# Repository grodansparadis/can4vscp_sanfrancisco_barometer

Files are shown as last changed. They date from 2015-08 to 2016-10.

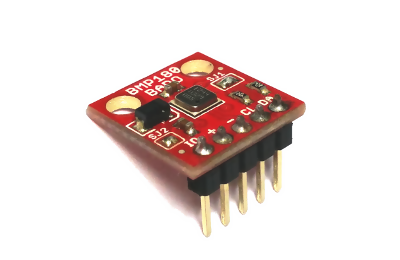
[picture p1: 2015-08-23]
docs/BMP180 Barometric Pressure Sensor Hookup - learn.sparkfun.com_files/52ce00f3ce395fc7238b4567.png

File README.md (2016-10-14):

<h1>CAN4VSCP San Franscisco - barometer module</h1>

VSCP Barometer module.

<hr>

This project is part of the <a href="http://www.vscp.org">VSCP (Very Simple Control Protocol) project</a>. 

<hr>

This project is licensed under the 
<a href="http://creativecommons.org/licenses/by-nc-sa/3.0/">Creative Commons open source license Attribution-NonCommercial-ShareAlike 3.0 Unported</a>. 
Other license options are available by conacting <a href="malto:info@grodansparadis.com">Paradis of the Frog AB</a>

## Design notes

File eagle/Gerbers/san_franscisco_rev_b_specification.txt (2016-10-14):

Ake Hedman
Grodans Paradis AB

Date:				2014-06-18
Part Number: 		San Francisco
Number of boards: 	120
Number of layers: 	2 
Material: 			FR4
Final Thickness:	1.6 mm
Final copper:		1/1oz
Surface treatment: 	ENIG
Unit Size:			72 x 42 mm
Panel Size:			154*126 mm
Unit/panel:			6
Solder Mask:		Green
Silk Screen: 		White	
Outline Profile:	CNC Routing + V-cut
X-out Allowed:		1
Stencil needed:		yes
Gerber layer for Stencil: Component Cream (pmc)

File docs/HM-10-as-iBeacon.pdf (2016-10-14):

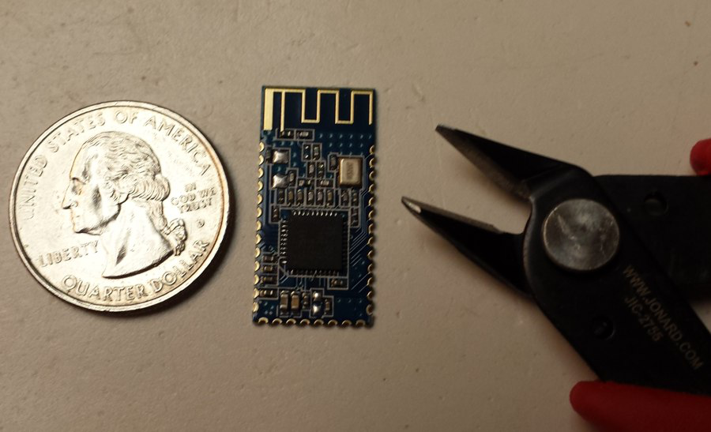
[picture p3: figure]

http://www.blueluminance.com/HM-10-as-iBeacon.pdf V3 | Page 1

## Using HM-10 BLE Modules as Low-Cost iBeacons

This document will describe how to use an HM-10 Bluetooth 4.0 module as an iBeacon. Although the HM-10 can also be used as a data link, a standalone sensor or control device, this document will not cover those other use cases.
The HM-10 is a readily available Bluetooth 4.0 module based on the Texas Instruments CC2540 or CC2541 Bluetooth low energy (BLE) System on Chip (SoC). The module design and firmware originated from the Jinan Huamao Technology Company (JNHuaMao), but is sold by various Chinese suppliers, and by several U.S. and European distributors.
The modules shown here were purchased directly from ITead Studio’s iMall web site for only US$6.50 each. They came pre-loaded with HM-10 Firmware version 526, but at the time I received them, version 528 (June 2014) was already available from the JNHuaMao download site, so I upgraded all the modules (more about how to do that later). As of September 2014 firmware version 531 was available.

The module is fairly small as seen in the photograph above. The contact spacing is 1.5 mm. Care should be taken when soldering wires to the module which will be necessary to connect it to a power source, and temporarily to a USB serial interface module and PC to configure the module as an iBeacon. The HM-10 is rated to operate at a supply voltage of 2.0 to 3.7 volts, and its I/O are 3.3V tolerant.

### Hardware Connections

Two wire connections are needed to supply power to the module and three temporary connections are needed to configure the module through a USB serial adapter.

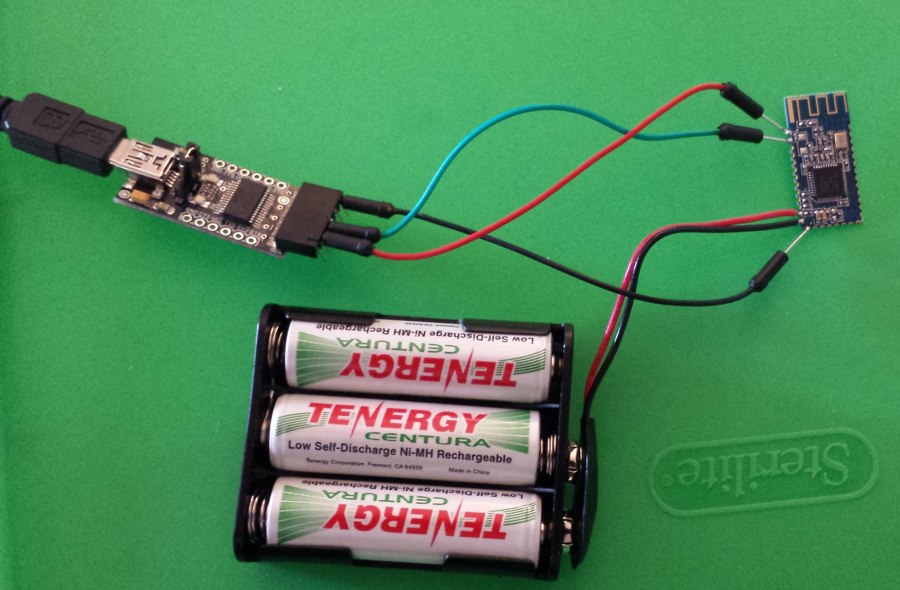
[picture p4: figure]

The photo above shows the module hooked up to a battery pack consisting of three NiMH rechargeable cells with a nominal output of 1.2V x 3 = 3.6V, and to a USB to TTL logic level RS232 serial adapter. If you are an Arduino enthusiast you probably already have one of these adapters, if not they are available for about US $15 online and from retailers like Fry’s and Microcenter, and come in different designs. The one in the photo is by OSEPP. If you are purchasing one, I suggest getting one that has a 3.3V/5.0V jumper or selector switch so that you can set it to supply the proper voltage for other projects. Do not worry if the adapter does not look exactly like the one in the photo.
When configured as described later in this article, the HM-10 draws an average of about 0.18 mA. The battery pack shown has a capacity of about 1800 mAh which would last 10,000 hours, or more than a year. If you want to build a very small iBeacon, you could use a single 240 mAh CR2032 coin cell which will last about 55 days. Battery holders for CR2032 coin cells are available. Note: if you are using alkaline cells, you must use a two-cell battery holder to keep the voltage within specifications (nominal 1.5V x 2 = 3.0V).

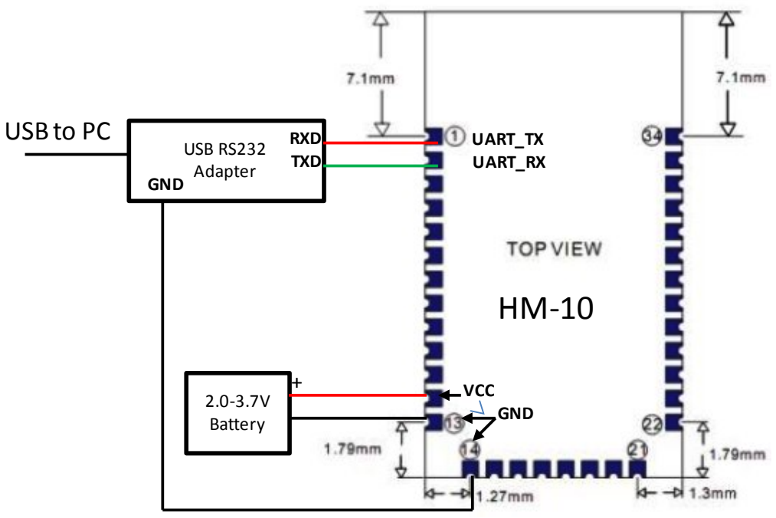
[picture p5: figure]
UART_TX UART_RX; VCC; GND; 2.0-3.7V Battery; USB RS232 Adapter; RXD TXD; USB to PC

The diagram above shows the connections in detail. The battery is connected to pins 12 (+) and 13 (-) of the module. The RS232 adapter receive data (RXD) connects to pin 1, and transmit data (TXD) connects to pin 2. (Note: The transmit and receive signals to the HM-10 are crossed. This is correct.) The ground pin of the adapter connects to pin 14.

### Using a Terminal Emulator to Talk to the HM-10

Once your hardware is ready you will want to be able to check if your HM-10 is working. With the battery and serial adapter connected to the HM-10, connect the USB cable of the adapter to your PC. If this is the first time you are using the adapter, you may be asked for a device driver for the module. In most cases the operating system will find the driver automatically (it may take a couple of minutes). If not, refer to the documentation that came with the device. If you can, take note of the COM port assigned to the adapter.
The HM-10 uses an AT command set that requires very unusual timing when manually typing in commands from the PC. The commands are not terminated by a carriage return or line feed, and rely on a very short delay after the command line has been entered to complete. Therefore I strongly recommend using the Arduino software serial monitor to talk to the HM-10. For most people reading this, the Arduino IDE is probably already installed on their PC. If it is not yet installed, please install version 1.0x (currently 1.05) available from http://arduino.cc/en/Main/Software. Once installed, start the program up.

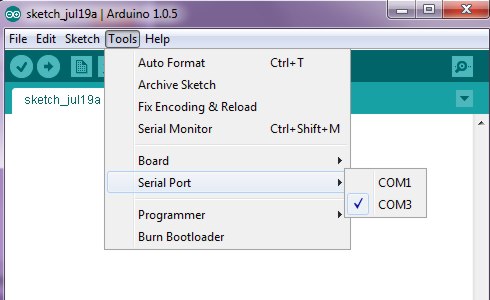
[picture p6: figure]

Under the tools menu pull down, select Serial Port, and then select the COM port corresponding to your serial adapter. In most cases this will be the highest numbered COM port available. See the screenshot above where the COM port is COM3.
Next launch the serial monitor by selecting the menu item under tools. At the bottom menu, select “9600 Baud” and “No line ending”. Now you can talk to the HM-10. Try typing in the command “AT” (without the quotation marks) followed by the Enter key. The HM-10 should respond with “OK”. The HM-10 does not terminate its output with a new line, so all its responses will be strung one after another.

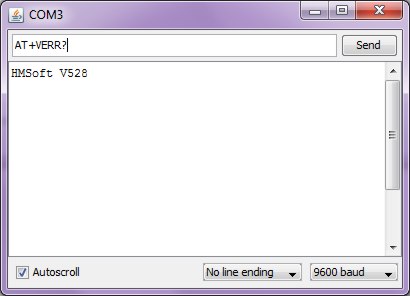
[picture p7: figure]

Next you can check the firmware version in your HM-10. Enter the command “AT+VERR?”. If you recently bought the HM-10 it should be version 526 or later. If so, you can skip the Firmware Update section below, and go directly to the iBeacon Configuration section. If you want the latest anyway, go ahead and update the firmware.

### Firmware Update

If your HM-10 needs a firmware update, you must download the appropriate version from the JNHuaMao web site. Determine which TI chip your HM-10 is using. It will either be a CC2540 (older units) or CC2541 (newer units). You can look at the square chip on the HM-10 under (use a magnifier if needed) and you should be able to read the markings.
Go to the download site at http://www.jnhuamao.cn/download_rom_en.asp?id=# Make sure you are downloading the correct version of the firmware! That would be for the HM-10, and for the TI chip you have on your board.
Unizp the firmware update file, and place all the contents in the same folder. You will see at least 3 files. One will be a readme.txt file with brief instructions. The second will be the firmware file with a .bin suffix. The third file will be the firmware update application .exe file for Windows (sorry Linux and Mac users). It will probably be named HMSoft.exe.
Before updating the HM-10 firmware, make sure you have reliable connections to the module, and that the wires and cables cannot be accidentally knocked loose. Keep pets and small children from the area where you are doing the firmware update to avoid accidental interruption of the update.
1. Using the Arduino serial monitor enter the command AT+SBLUP
The HM-10 should respond with OK+SBLUP. At this point the HM-10 is waiting for the firmware update.
2. Exit the serial monitor program.
3. Next, launch the firmware update program (the .exe file that you extracted from the zip file) most likely called HMSoft.exe.
4. In the COM Port field, enter the COM port number of the port connected to your HM-10. For example if it is COM3, enter 3 in the field.
5. Click on the “…” button for the Image File field, and select the .bin file name of the file that came in the zip file: HMSoft.bin.
6. Finally, click on Load Image button.
7. The firmware update will proceed and will take a couple of minutes. Do not interrupt the update process. Do not do anything else on the PC while the update is taking place to reduce the chances the process will be interrupted.

8. When verification is complete, it may take a few seconds before the Download completed successfully message is displayed.

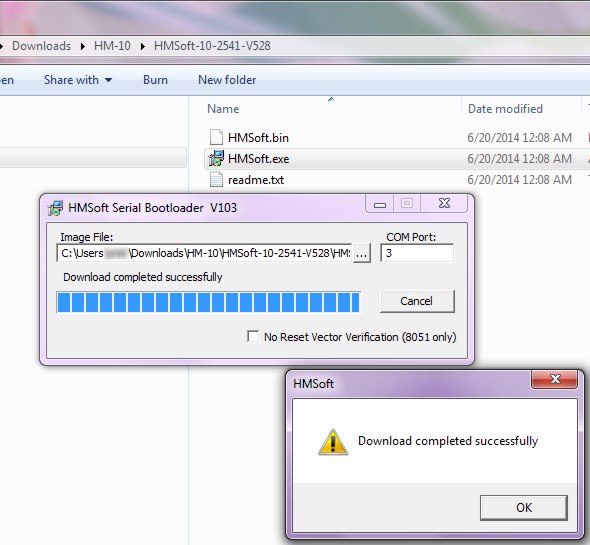
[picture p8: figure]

The screenshot above shows an example of a successfully concluded firmware update. When finished, exit the firmware update program, and re-launch the Arduino serial monitor program.

### iBeacon Configuration

You have to type in a few commands to the HM-10 to configure it as an iBeacon. Use the Arduino serial monitor program to do this. In the following list, the bold initial text is the command you should type into the HM-10 and the rest is a comment on what it does. Each command will be acknowledged with an OK…
1. AT+RENEW | Restores factory defaults
2. AT+RESET | Reboot HM-10

3. AT | Wait for OK
4. AT+MARJ0x1234 Set iBeacon Major number to 0x1234 (hexadecimal)
5. AT+MINO0xFA01 Set iBeacon Minor number to 0xFA01 (hexadecimal)
6. AT+ADVI5 Set advertising interval to 5 (546.25 milliseconds)
7. AT+NAMEDOPEY Set HM-10 module name to DOPEY. Make this unique.
8. AT+ADTY3 | Make non-connectable (save power)
9. AT+IBEA1 | Enable iBeacon mode
10.AT+DELO2 | iBeacon broadcast-only (save power)
11.AT+PWRM0 | Enable auto-sleep. This reduces power from 8 to 0.18 mA
12.AT+RESET | Reboot
Note: The values of the parameters in red should be what you want them to be. The above are just examples.
After sending it this set of commands, the HM-10 should be visible on your iDevice or Android device (using you favorite iBeacon App) as an iBeacon. You can select the appropriate Major and Minor Numbers in steps 4 and 5. The Major number is the same in an area (e.g. a store or building) and the Minor number uniquely identifies the iBeacon. The above procedure does not alter the default HM-10 UUID which is a standard proximity UUID. If you want to change it, you may do so using the AT+IBE0, AT+IBE1, AT+IBE2 and AT+IBE3 commands. The 16 byte UUID is divided into 4 byte chunks and each one is altered with a different command. The table below illustrates which part of the UUID is updated with each of the 4 commands.
UUID: 74278BDA-B644-4520-8F0C-720EAF059935
AT+IBE074278BDA | AT+IBE1B6444520 | AT+IBE28F0C720E | AT+IBE3AF059935

### Removing the Programming Cable

When you are convinced the HM-10 is configured the way you want, you can unsolder the connection to the serial adapter, and leave the power connector in place.

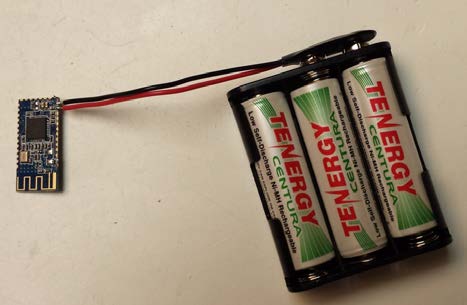
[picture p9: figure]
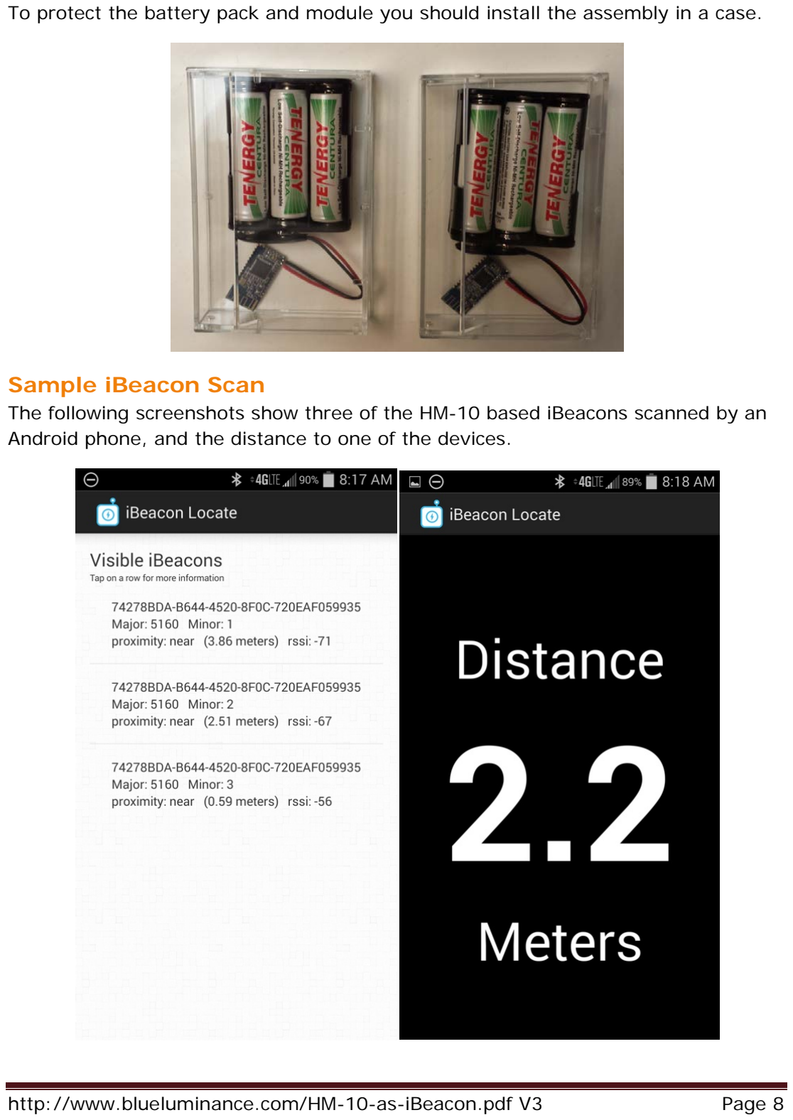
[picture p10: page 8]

To protect the battery pack and module you should install the assembly in a case.

### Sample iBeacon Scan

The following screenshots show three of the HM-10 based iBeacons scanned by an Android phone, and the distance to one of the devices.

### Using the HM-10 as an iBeacon Proximity Device

The following eight UUIDs are built into Apple AirLocate as proximity devices. Use these to ensure compatibility with iOS apps that use AirLocate.

### E2C56DB5-DFFB-48D2-B060-D0F5A71096E0 5A4BCFCE-174E-4BAC-A814-092E77F6B7E5

## 74278BDA-B644-4520-8F0C-720EAF059935 HM-10 Default

### 112ebb9d-b8c9-4abd-9eb3-43578bf86a41 22a17b43-552a-4482-865f-597d4c10bacc 33d8e127-4e58-485b-bee7-266526d8ecb2 44f506a4-b778-4c4e-8522-157aac0efabd 552452fe-f374-47c4-bfad-9ea4165e1bd9

### Waking Up the HM-10

When the HM-10 is in auto-sleep mode, it will quickly go to sleep when powered up or rebooted. After sending it the AT+PWRM0 command and it is restarted, the HM-10 will no longer respond to AT commands. To wake up the device, send it a long line of random alphabetic characters which is 80 characters or more. It will wake up and respond with OK+WAKE. If you want to work with the device for a while, send it an AT+PWRM1 command so it does not sleep on you. You can then send it an AT+PWRM0 when you are done to reduce power consumption.

### References and Web Links

1. iBeacon general article: http://en.wikipedia.org/wiki/IBeacon
2. HM-10 Datasheet: http://www.jnhuamao.cn/bluetooth40_en.zip
3. HM-10 Firmware: http://www.jnhuamao.cn/download_rom_en.asp?id=#
4. USB Serial adapters:
https://www.sparkfun.com/products/718http://www.adafruit.com/product/284http://www.frys.com/product/6997547
5. HM-10 for sale:
http://imall.iteadstudio.com/im130614001.htmlhttp://www.ebay.com/sch/i.html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
6. Locate iBeacon for iOS
https://itunes.apple.com/us/app/locate-for-ibeacon/id738709014?mt=8
7. iBeacon Scavenger Hunt
https://itunes.apple.com/us/app/beacon-scavenger-hunt/id821092269?id=com.radiusnetworks.scavengerhunt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 (https://play.google.com/store/apps/details?id=com.radiusnetworks.scavengerhunt&hl=en)
8. iBeacon Scanner for Android https://play.google.com/store/apps/details?id=kr.co.ixsoft.ibeacon.scanner&hl=en (https://play.google.com/store/apps/details?id=kr.co.ixsoft.ibeacon.scanner&hl=en)

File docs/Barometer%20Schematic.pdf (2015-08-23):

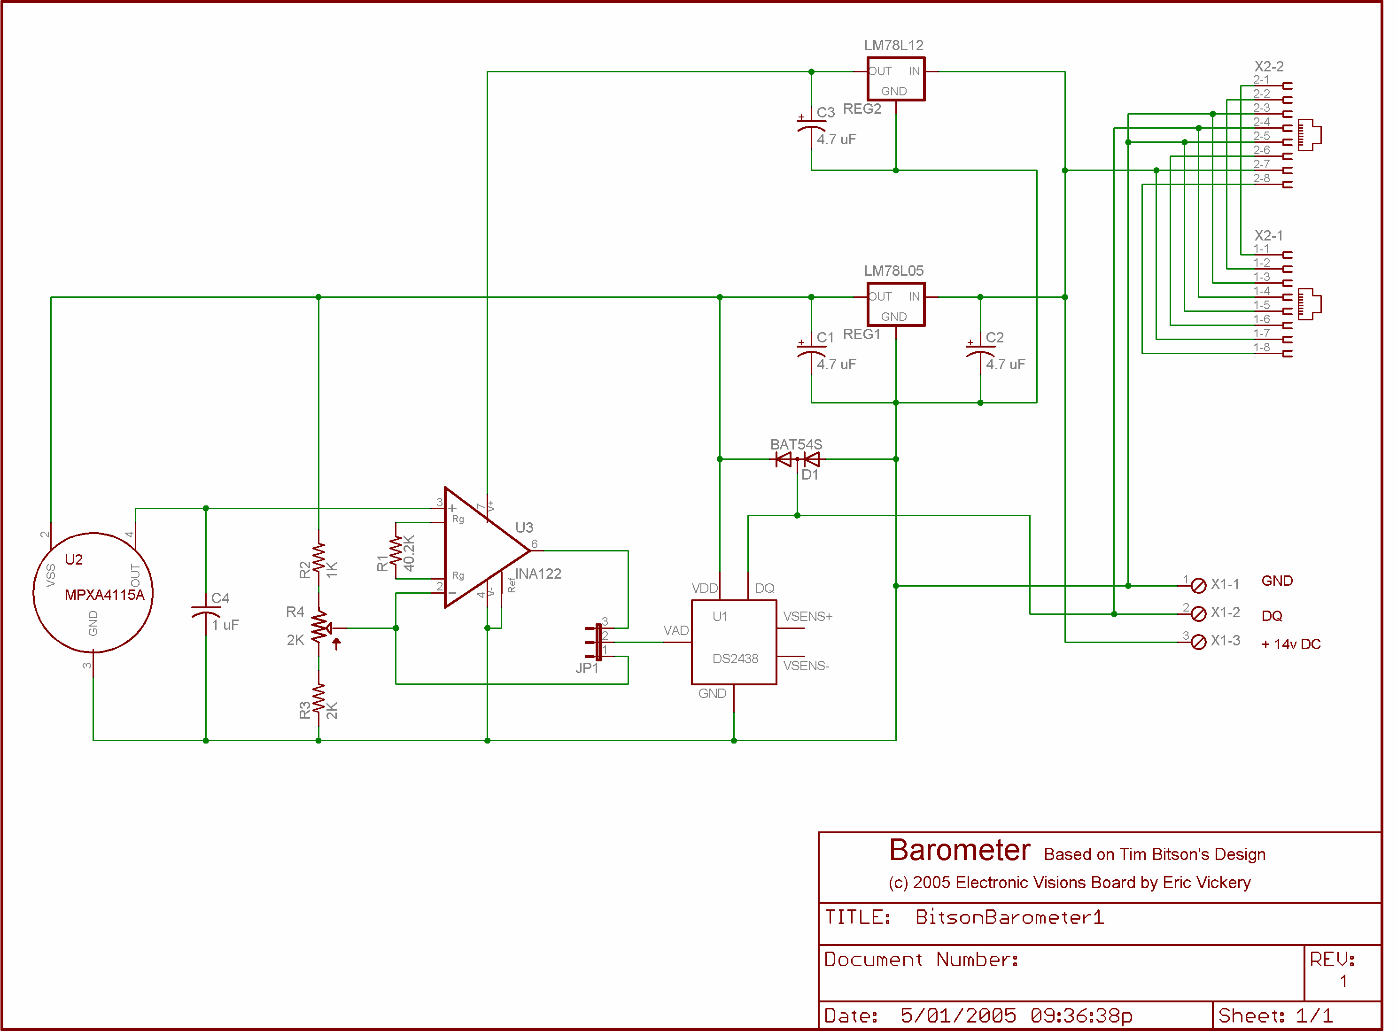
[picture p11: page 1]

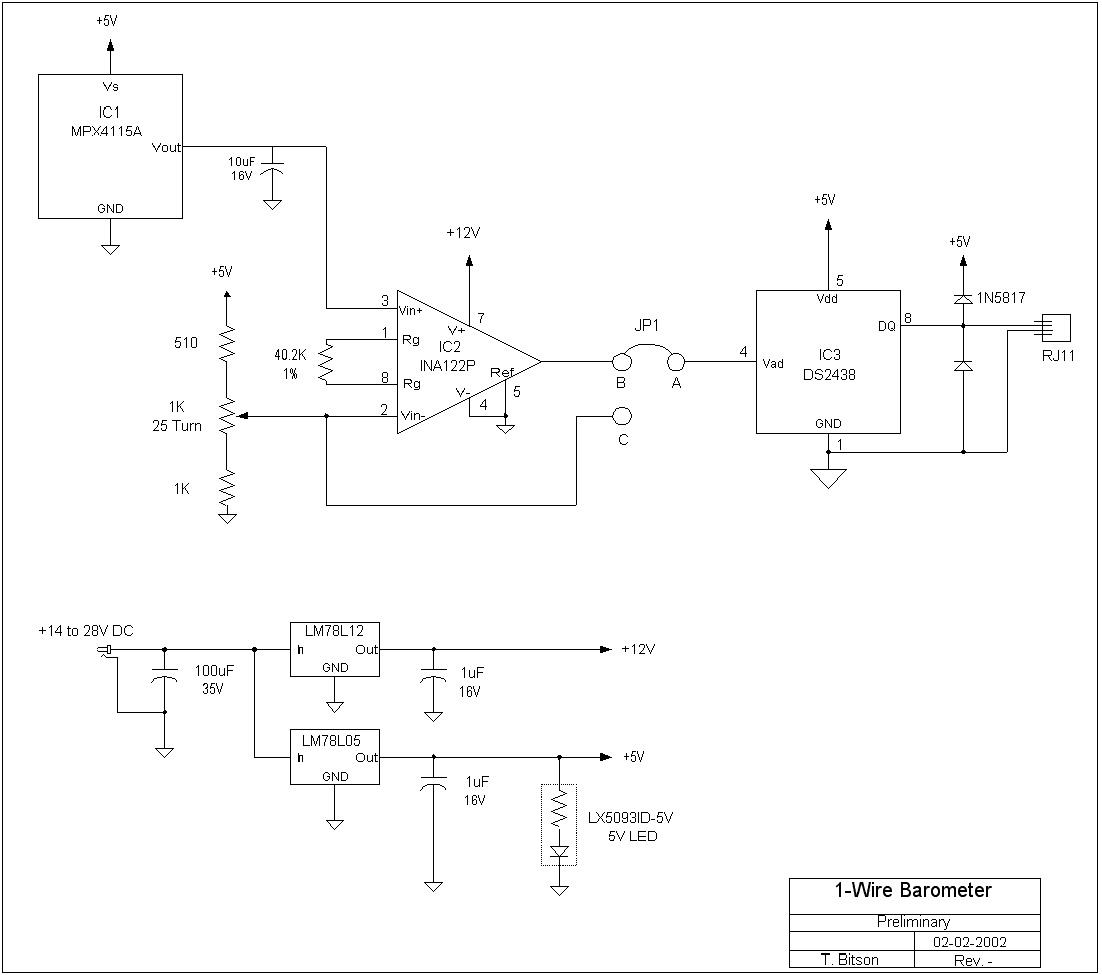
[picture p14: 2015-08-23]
docs/1WireBarometer.jpg

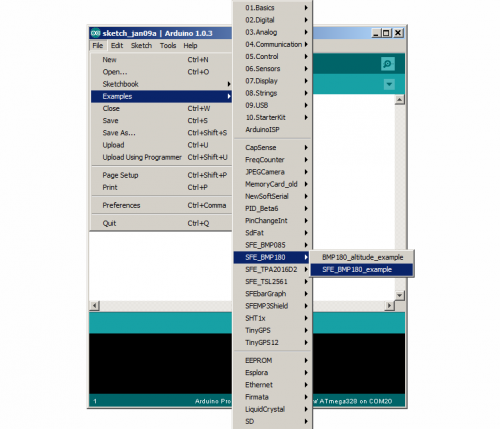
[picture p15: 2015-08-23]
docs/BMP180 Barometric Pressure Sensor Hookup - learn.sparkfun.com_files/52cec902ce395f1c708b4569.png

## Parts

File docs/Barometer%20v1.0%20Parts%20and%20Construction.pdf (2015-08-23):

## Barometer v1.0 Parts List

ID | Description | DigiKey Part# | Mouser Part#
X1 | 3-pin Screw Term Block 3.5mm | ED1515-ND
X2 | RJ-45 Jack 2 Port | A9013-ND
U1 | DS2438Z | Available from Dallas
U2 | MPXA4115A | MPXA4115AC6U-ND
U3 | INA122U | INA122U-ND
REG1 | L78L05 | NJM78L05UA-ND | 511-L78L05ACU
REG2 | L78L12 | NJM78L12UA-ND | 511-L78L12ACU
C1,C2,C3 | 4.7 uF Electrolytic | PCE3011CT-ND | 661-MKA35VC4R7M
C4 | 1 uF Ceramic | PCC2319CT-ND
D1 | BAT54S | BAT54SWT1OSCT-ND 625-BAT54S
R1 | 40.2K 1/4W 1% | 311-40.2KFCT-ND | 71-CRCW1206-40.2K
R2 | 1K 1/4W 1% | 311-1.00KFCT-ND | 71-CRCW1206-1.0K
R3 | 2K 1/4W 1% | 311-2.00KFCT-ND | 71-CRCW1206-2.0K
R4 | 2K Pot Multi-turn | | 72-T93YA-2K
JP1 | 3 pin header | WM6707-ND | 571-1029727

Mouser is usually cheaper than DigiKey but the terminal blocks are cheaper at DigiKey.

## Construction Tips

- Place all surface mount components first.
- Observe the polarity of C1, C2 and C3
- REG1 is marked BCF3
- REG2 is marked 8KE8
- D1 is marked L44
- R1 is marked 4022
- R2 is marked 1001
- R3 is marked 2001
- C4 is brown and not marked
- Install U2 before C1, C2 or C3
- If a water resistant coating (like liquid electrical tape) is going to be used make sure to not apply it to the MPXA4115A pressure sensor.

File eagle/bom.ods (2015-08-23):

Partlis | t exported from | C:/Users/akhe/Docu | ments/develop | ment/hardware_zeus/can4vscp/sanfrancisco_baromete | r/eagle/sanfrancisco_ba | rometer_r | ev_a.sch at 2011-10- | 06 16:49:32
Part | Value | Device | Package | Description | Description | Supplier | Partnumber | Price
1N5819 | S1D | DIODE-SMB | SMB | DIODE | Protection diod | Digikey | 1N5819HW-FDICT-ND | 3,84
C1 | 100uF | CPOL-EUD | PANASONIC_D | POLARIZED CAPACITOR, European symbol | Elektrolytkondensator | Digikey | PCE3951CT-ND | 5,04
C2 | 330uF | CPOL-EUD | PANASONIC_D | POLARIZED CAPACITOR, European symbol | Elektrolytkondensator | Digikey | PCE4164CT-ND | 4,4
C3 | 100nF | CNP-0805 | 805 | NON-POLARIZED CAP | Avstörningskondensator | Bejoken | 522526 | 0,07
C4 | 15pF | C-EUC0805 | C0805 | CAPACITOR, European symbol | Kondensator | Bejoken | 522419 | 0,11
C5 | 0.1uF | C-EUC0805 | C0805 | CAPACITOR, European symbol | Avstörningskondensator | Bejoken | 522526 | 0,07
C6 | 15pF | C-EUC0805 | C0805 | CAPACITOR, European symbol | Kondensator | Bejoken | 522419 | 0,11
C7 | 0.1uF | C-EUC0805 | C0805 | CAPACITOR, European symbol | Avstörningskondensator | Bejoken | 522526 | 0,07
C8 | 0.1uF | C-EUC0805 | C0805 | CAPACITOR, European symbol | Avstörningskondensator | Bejoken | 522526 | 0,07
C9 | 1uF | C-EUC0805 | C0805 | CAPACITOR, European symbol | Capacitor | Bejoken | 522592 | 0,16
C10 | 1uF | C-EUC0805 | C0805 | CAPACITOR, European symbol | Capacitor | Bejoken | 522592 | 0,16
D1 | S1D | DIODE-SMB | SMB | DIODE | Protection diod | Digikey | 1N5819HW-FDICT-ND | 3,84
D2 | NUP2105L | DIODE-2CA|ACSOT23 | SOT23 | Dual DIODE Cathode-Anode|Anode-Cathode | Tansient protection | Digikey | NUP2105LT1GOSCT-ND | 4
IC1 | PIC18F2580 | PIC18LF252-I/SO | SO28 | 18F252, 28 pin, 32Kb prog, 1536 data, 256 EEPROM | Processor | Digikey | PIC18F2580-I/SO-ND | 60,96
IC3 | MCP2551SN | MCP2551SN | SO-08 | High Speed CAN tranceiver | CAN tranceiver | Digikey | MCP2551-I/SN-ND | 8,96
IC4 | LM2575S | LM2575S | TO263-5 | National Semiconductor 1.0A "Simple Switcher"(c) | Simpleswitcher | Digikey | LM2575S-3.3/NOPB-ND | 23,76
J2 | A00-108-220-450 | A00-108-220-450 | RJ-45 |  | RJ-45 connector | Digikey | 151-1099-nd | 5,6
J3 |  | MA06-1 | MA06-1 | PIN HEADER | Enkel stiftlist | Digikey | SAM1035-50-ND | 0,33
J4 |  | MA04-1 | MA04-1 | PIN HEADER | Enkel stiftlist | Digikey | SAM1035-50-ND | 0,33
L1 | 330 uH | DO3316P | DO3316P | COILCRAFT | Drossel 330u | Digikey | 553-1514-1-nd | 10,24
LED1 | green | LEDCHIP-LED0805 | CHIP-LED0805 | LED | LED Grön | Digikey | 475-1410-1-nd | 0,88
LED9 | red | LEDCHIP-LED0805 | CHIP-LED0805 | LED | LED Röd | Digikey | 475-1415-1-ND | 0,88
Q1 | 10 MHz | HC-49S | 9C | Digikey 887-1050-1-nd | 10 MHz Crystal | Digikey | 887-1050-1-d | 4,24
R2 | 10K | R-EU_R0805 | R0805 | RESISTOR, European symbol | Resistor | Bejoken | 454676 | 0,01
R3 | 1K | R-EU_R0805 | R0805 | RESISTOR, European symbol | Resistor | Bejoken | 454650 | 0,01
R4 | 10K | R-EU_R0805 | R0805 | RESISTOR, European symbol | Resistor | Bejoken | 454676 | 0,01
R11 | 1K | R-EU_R0805 | R0805 | RESISTOR, European symbol | Resistor | Bejoken | 454650 | 0,01
S1 |  | 31-XX | B3F-31XX | OMRON SWITCH | Init switch | Elfa | 35-677-65 | 2,89
U$1 | MPL115A1 | MPL115A1 | LGA8 |  | Barometer | Digikey | MPL115A1T1CT-ND | 17,68
 |  |  |  |  |  |  |  | 158,73

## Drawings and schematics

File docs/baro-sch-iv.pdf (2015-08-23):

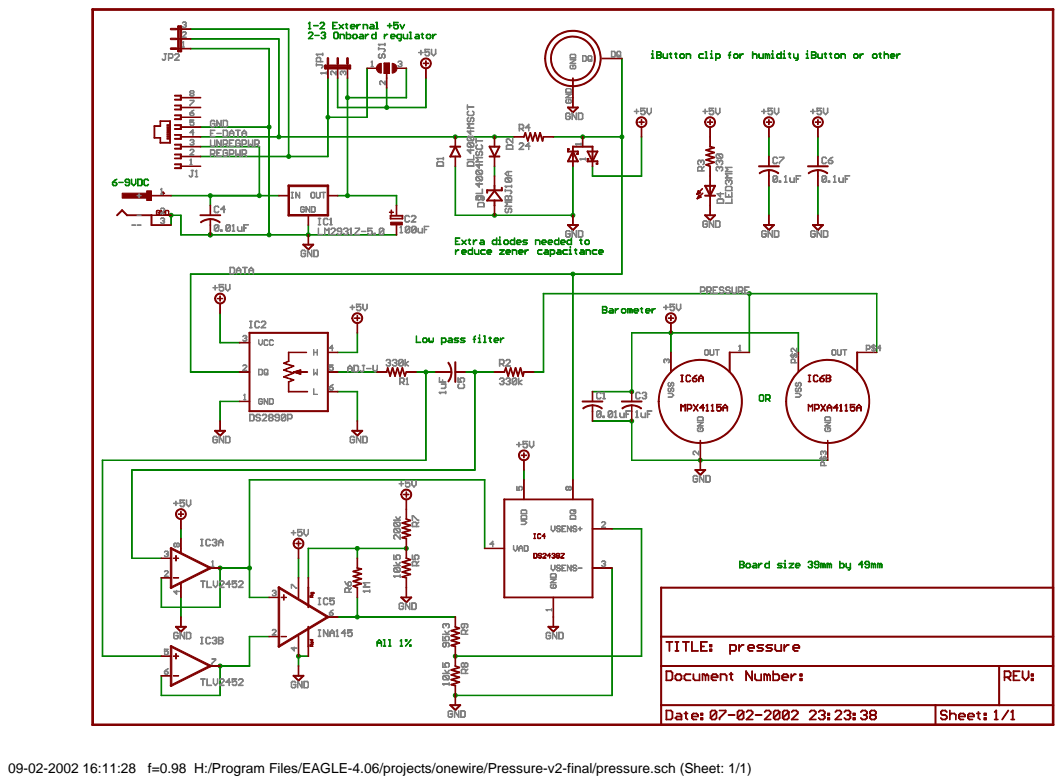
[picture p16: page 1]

09-02-2002 16:11:28 f=0.98 H:/Program Files/EAGLE-4.06/projects/onewire/Pressure-v2-final/pressure.sch (Sheet: 1/1)

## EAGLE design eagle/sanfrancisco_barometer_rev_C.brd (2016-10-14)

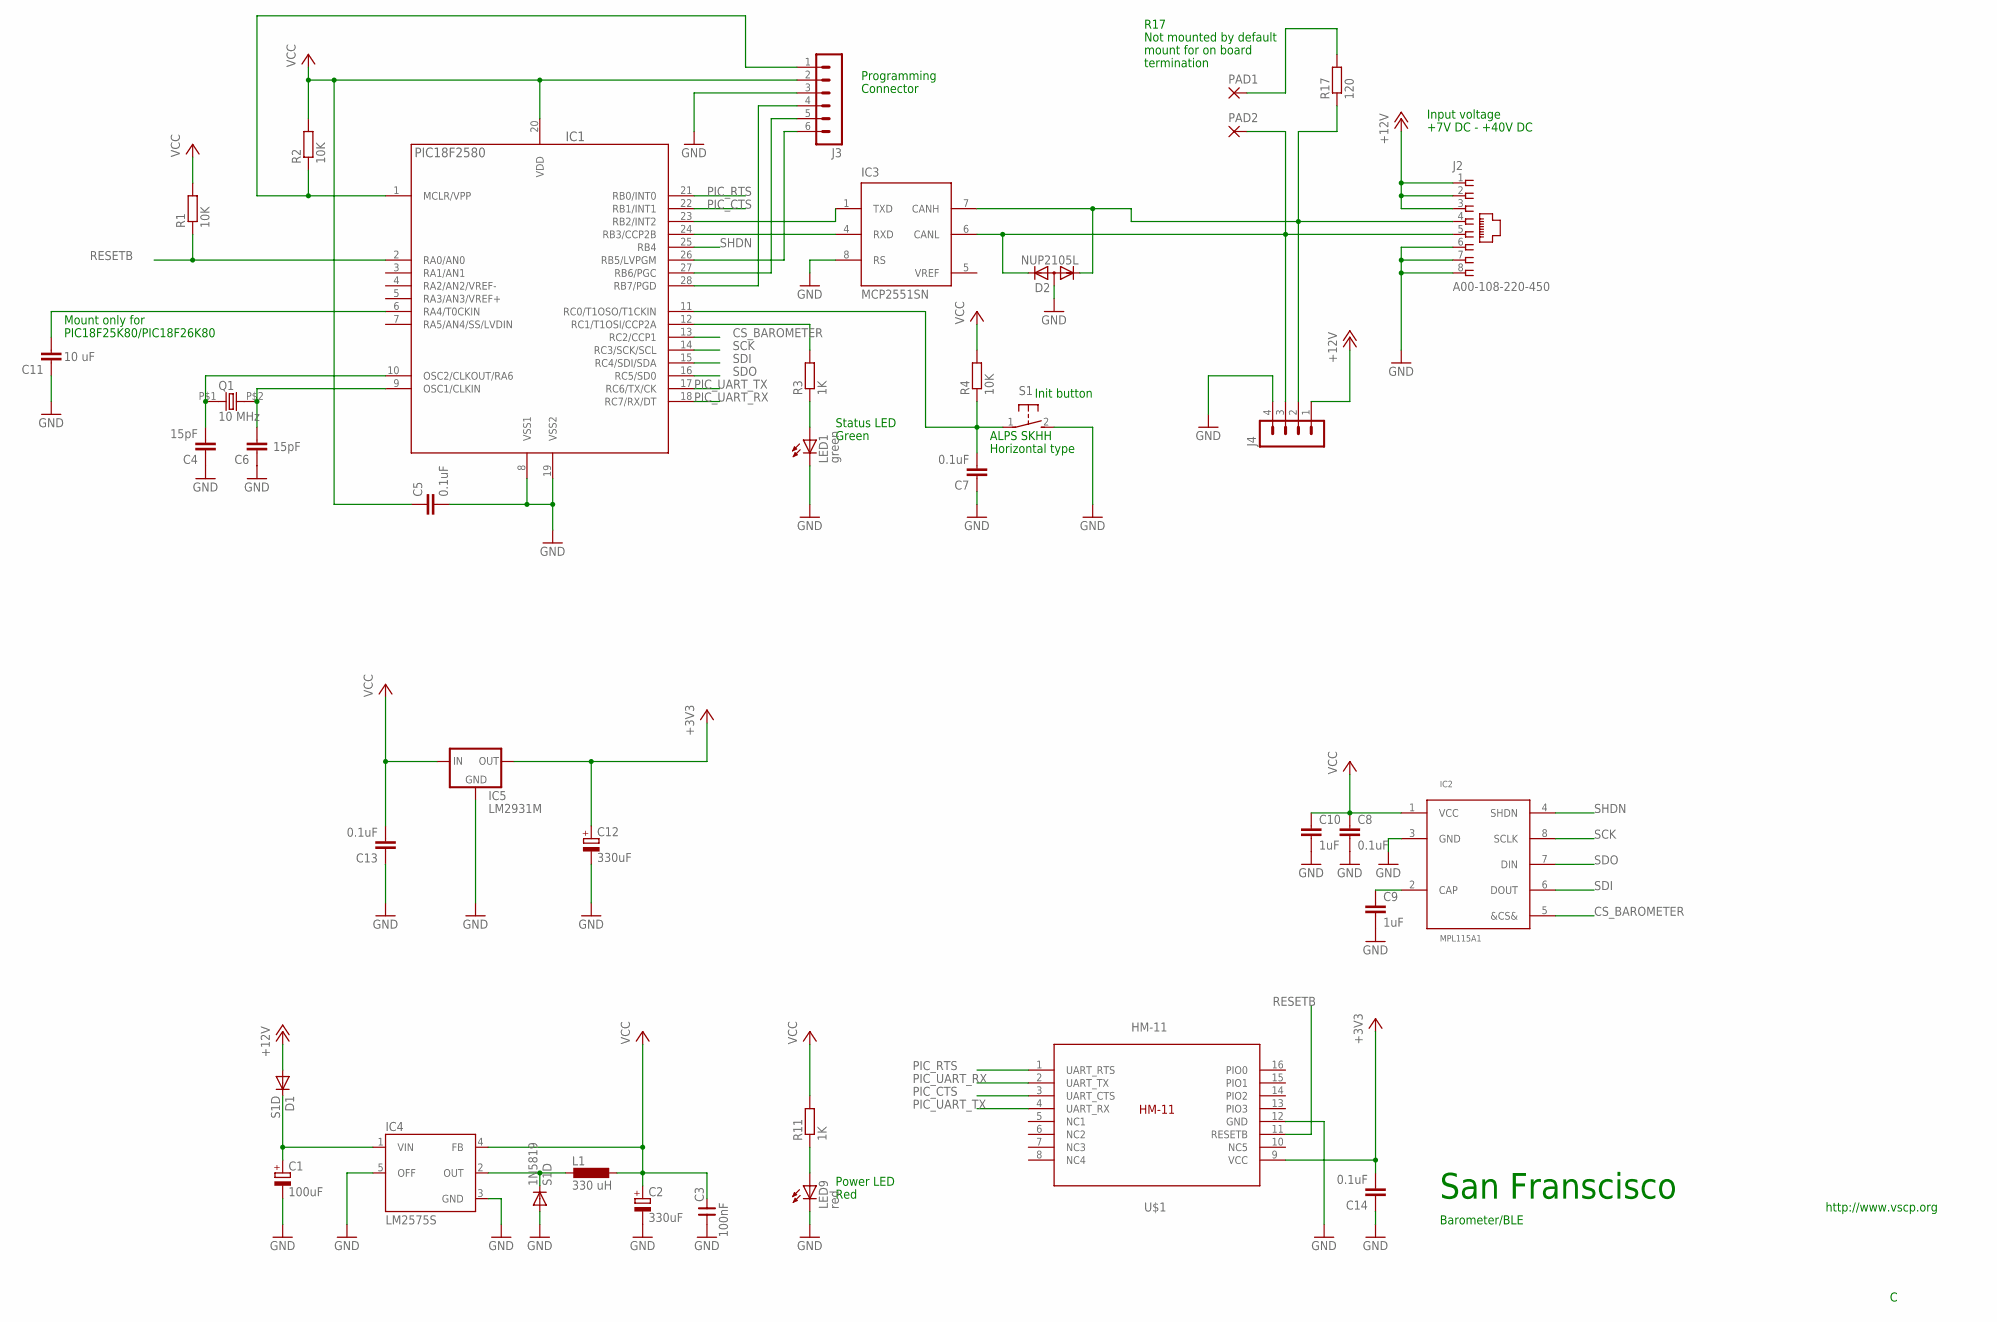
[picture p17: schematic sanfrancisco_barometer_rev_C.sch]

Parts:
1N5819: S1D; SOD123
C1: 100uF; PANASONIC_D
C2, C12: 330uF; PANASONIC_D
C3: 100nF; 0805
C4, C6: 15pF; C0805
C5, C7, C8, C13, C14: 0.1uF; C0805
C9, C10: 1uF; C0805
C11: 10 uF; C0805
D1: S1D; SOD123
D2: NUP2105L; SOT23
IC1: PIC18F2580; SO28
IC2: MPL115A1; LGA8
IC3: MCP2551SN; SO-08
IC4: LM2575S; TO263-5
IC5: LM2931M; SO08
J2: A00-108-220-450; RJ-45
J3: MA06-1
J4: MA04-1
L1: 330 uH; DO3316P
LED1: green; CHIP-LED0805
LED9: red; CHIP-LED0805
PAD1, PAD2: 1,6/0,8
Q1: 10 MHz; 9C
R1, R2, R4: 10K; R0805
R3, R11: 1K; R0805
R17: 120; R0805
S1: 31-XX; B3F-31XX
U$1: HM-11

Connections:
+3V3: C12.+, C14.2, IC5.1 (OUT), U$1.9 (VCC)
+12V: D1.A, J2.1, J2.2, J2.3, J4.1
CANL: D2.2 (K2), IC3.6 (CANL), J2.5, J4.3, PAD2.1
CS_BAROMETER: IC1.13 (RC2/CCP1), IC2.5 (&CS&)
GND: 1N5819.A, C1.-, C2.-, C3.1, C4.1, C5.2, C6.1, C7.1, C8.2, C9.2, C10.2, C11.1, C12.-, C13.1, C14.1, D2.3 (A), IC1.8 (VSS1), IC1.19 (VSS2), IC2.3 (GND), IC3.2 (VSS), IC3.8 (RS), IC4.3 (GND), IC4.5 (OFF), IC5.2 (GND), J2.6, J2.7, J2.8, J3.3, J4.4, LED1.C, LED9.C, S1.2 (S), U$1.12 (GND)
unnamed: 1N5819.C, IC4.2 (OUT), L1.1
unnamed: C4.2, IC1.10 (OSC2/CLKOUT/RA6), Q1.P$1 (1)
unnamed: C1.+, D1.C, IC4.1 (VIN)
unnamed: IC1.12 (RC1/T1OSI/CCP2A), R3.2
unnamed: LED1.A, R3.1
unnamed: C7.2, IC1.11 (RC0/T1OSO/T1CKIN), R4.1, S1.1
unnamed: C6.2, IC1.9 (OSC1/CLKIN), Q1.P$2 (2)
unnamed: C11.2, IC1.6 (RA4/T0CKIN)
unnamed: C9.1, IC2.2 (CAP)
unnamed: IC1.1 (MCLR/VPP), J3.1, R2.1
unnamed: IC1.28 (RB7/PGD), J3.4
unnamed: IC1.27 (RB6/PGC), J3.5
unnamed: IC1.26 (RB5/LVPGM), J3.6
unnamed: PAD1.1, R17.2
unnamed: LED9.A, R11.1
unnamed: D2.1 (K1), IC3.7 (CANH), J2.4, J4.2, R17.1
PIC_CTS: IC1.22 (RB1/INT1), U$1.3 (UART_CTS)
PIC_RTS: IC1.21 (RB0/INT0), U$1.1 (UART_RTS)
PIC_UART_RX: IC1.18 (RC7/RX/DT), U$1.2 (UART_TX)
PIC_UART_TX: IC1.17 (RC6/TX/CK), U$1.4 (UART_RX)
RESETB: IC1.2 (RA0/AN0), R1.1, U$1.11 (RESETB)
RXCAN: IC1.24 (RB3/CCP2B), IC3.4 (RXD)
SCK: IC1.14 (RC3/SCK/SCL), IC2.8 (SCLK)
SDI: IC1.15 (RC4/SDI/SDA), IC2.6 (DOUT)
SDO: IC1.16 (RC5/SD0), IC2.7 (DIN)
SHDN: IC1.25 (RB4), IC2.4 (SHDN)
TXCAN: IC1.23 (RB2/INT2), IC3.1 (TXD)
VCC: C2.+, C3.2, C5.1, C8.1, C10.1, C13.2, IC1.20 (VDD), IC2.1 (VCC), IC3.3 (VDD), IC4.4 (FB), IC5.8 (IN), J3.2, L1.2, R1.2, R2.2, R4.2, R11.2
VREF: IC3.5 (VREF)

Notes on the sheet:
Init button
Status LED
Programming
Connector
ALPS SKHH
Horizontal type
San Franscisco
http://www.vscp.org
Input voltage
+7V DC - +40V DC
Power LED
Red
Green
Mount only for
PIC18F25K80/PIC18F26K80
Not mounted by default
mount for on board
termination
R17
Barometer/BLE

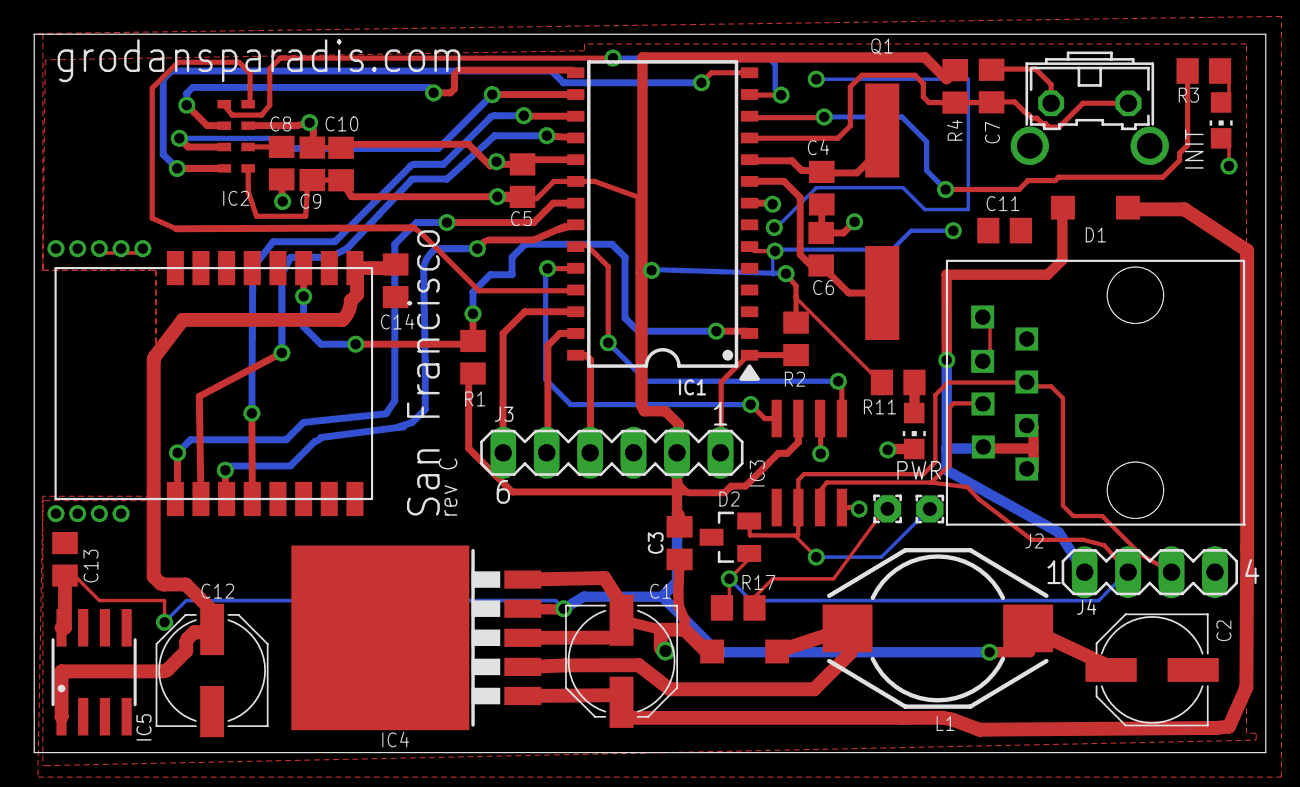
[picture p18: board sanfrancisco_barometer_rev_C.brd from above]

Board: 2 copper layers, 72.0 x 42.0 mm, 39 parts (0 on the bottom side), 33 nets.

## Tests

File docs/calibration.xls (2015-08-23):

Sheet: Startup
Lo | Hi
0 | 7.62
0 | 0
0 | 0
0 | 0
0 | 0
0 | 0
0 | 0
0 | 0
0 | 0
0 | 0
0 | 0
0 | 0
0 | 0
0 | 0
0 | 0
0 | 0
 | half | 4.0205 |  | vin | out
 |  |  | low | 3.792 | 2.03 |  | 3.792 | 1.94
 |  |  |  | 4.02 | 4.2 |  | 4.02 | 4.73
 |  |  |  | 4.24 | 6.36 | 4.195 | 4.24 | 7.35 | 4.645
 |  |  |  | 3.792 | 2.01 |  | 3.792 | 1.99
 |  |  |  | 4.02 | 4.68 |  | 4.02 | 4.79
 |  |  |  | 4.24 | 7.26 | 4.635 | 4.24 | 7.46 | 4.725

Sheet: BOM data
Data from BOM site
Date | Time | Voltage Reading | Lucas Heights | Bankstown | Airport | Average | Fit Equation | m | b
 |  |  |  |  |  |  |  | 18.404 | 910
2004-04-29 | 22.10 | 5.26 | 1006.8 | 1007.1 | 1006.3 | 1006.7 | 1006.8
2004-04-30 | 7.30 | 5.01 | 1001.1 | 1002.0 | 1001.7 | 1001.6 | 1002.2
2004-04-30 | 8.53 | 5.29 | 1006.1 | 1007.5 | 1007.6 | 1007.1 | 1007.4
2004-05-01 | 6.00 | 5.38 | 1008.7 | 1009.2 | 1009.7 | 1009.2 | 1009.0
2004-05-01 | 8.26 | 5.46 | 1010.3 | 1010.7 | 1010.3 | 1010.4 | 1010.5
2004-05-01 | 10.09 | 5.43 | 1009.9 | 1010.1 | 1009.5 | 1009.8 | 1009.9
2004-05-01 | 13.06 | 5.29 | 1007.7 | 1008.1 | 1008.1 | 1008.0 | 1007.4
2004-05-01 | 16.07 | 5.31 | 1007.4 | 1008.3 | 1008.1 | 1007.9 | 1007.7
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

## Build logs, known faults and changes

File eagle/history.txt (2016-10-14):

San Fransisco
=============

2016-04-06 - AKHE Remopved VCC connection V-CAP
REV-C -----------------------------------------------------------------------
2014-06-19 - AKHE Fixed dimensions
2014-06-18 - AKHE Off to factory
2014-06-02 - AKHE Added missing power to the C11 resistor. 
2011-12-20 - AKHE Added termination resistor. Leave unpopulated.
2011-11-17 - AKHE Added 1uF capacitor on uP pin 6 forPIC18F66K80 compability
2011-11-15 - AKHE Move L1 so it fits on the board.
2011-11-10 - AKHE Packages for D1/D2 updatet to SOD123 from SMDB
2011-11-10 - AKHE CANH should be on pin 4 of RJ-45
2011-11-10 - AKHE Rev B

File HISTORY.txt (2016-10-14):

160404 AKHE - Changed value of C14 to 10uF

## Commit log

2015-08-23 Added schema for San Franscisco
    [BaroCalcs.xls, bom.ods, calibration.xls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]
2016-10-14 Changed component symbols
    [sanfrancisco_barometer_rev_C.brd, sanfrancisco_barometer_rev_C.sch]
